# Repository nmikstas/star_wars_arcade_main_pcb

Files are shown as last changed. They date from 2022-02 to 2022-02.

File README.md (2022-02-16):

# star_wars_arcade_main_pcb
The source files for the reproduction of the 1983 Star Sars Arcade main PCB. The PCB is designed with Kicad. This project is complete and the PCB is verified working!

# Folder Structure
* BOM - Bill of materials for the main PCB
* Gerbers -The gerber files for the main PCB
* pcb - The Kicad design files for the main PCB

# PCB Specifications
* Layers: 2
* Dimensions: 293mm X 525mm
* Different PCB Design: 1
* PCB Thickness: 1.6mm
* Surface Finish: HASL
* Castellated Holes: No
* Copper Weight: 1oz.

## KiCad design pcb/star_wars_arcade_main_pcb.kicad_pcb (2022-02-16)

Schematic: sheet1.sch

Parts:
A_6, A_7: LS165A; DIP16
A_8: LS74; DIP14
A_9: LS164A; DIP14
B/C_0: LS138; DIP16
B_1: LS244B; DIP20
B_5: LS86; DIP14
B_6, B_7: LS165A; DIP16
B_8: LS385; DIP20
B_9: LS164A; DIP14
C1, C4, C5, C7, C8, C9, C10, C11, C12, C13, C14, C15, C16, C17, C18, C19, C20, C21, C22, C23, C24, C45, C46, C47, C48, C52, C53, C54, C55, C56, C57, C58, C59, C60, C61, C62, C63, C64, C65, C66, C67, C68, C69, C70, C71, C72, C73, C74, C75, C76, C77, C78, C79, C80, C81, C82, C83, C84, C85, C86, C87, C88, C89, C90, C91, C92, C95, C96: .1uf; GenericComp
C2: 100pf; CapBrown
C3: 39pf; CapBrown
C49, C50, C51: 100uf 35V; LargeCap
C93: 10uf 25V; Cap1
C94: 4.7uf; Cap1
CR1, CR3: 1N914; GenericComp
CR2: BLUE; LED
CR4, CR5, CR6: BLUE LED; LED
C_1: LS244C; DIP20
C_2: 68B09E; DDIP40
C_5: LS164A; DIP14
C_6, C_7: LS384; DIP16
C_8: LS08; DIP14
C_9, C_10: LS161; DIP16
D/E0: LS245A; DIP20
D_3: LS191_; DIP16
D_4, D_6, D_7: LS299; DIP20
D_5: LS164A; DIP14
D_8: LS00; DIP14
D_9: LS161; DIP16
E/F_2: LS244D; DIP20
E_1: x2212; DIP18
E_3: LS191_; DIP16
E_4: LS245A; DIP20
E_5, E_6: LS08; DIP14
E_7: LS00; DIP14
E_8: S02; DIP14
E_9: LS244; DIP20
F/H_2: 137211; DDIP24
F_1: 27128; DIP28
F_3: LS191_; DIP16
F_4: LS245A; DIP20
F_5: RAM; DDIP24
F_6: LS153A; DIP16
F_7: LS00; DIP14
F_8: S10; DIP14
F_9: LS244; DIP20
H/J_1: 2764; DIP28
H_3: LS157A; DIP16
H_4: LS245A; DIP20
H_5: RAM; DDIP24
H_6: LS191_; DIP16
H_7: PROM; DIP18
H_8: LS74; DIP14
H_9: LS244E; DIP20
J16: Aud_Conn; Aud_Con
J17: Main_Connector; J17
J18: Cat_Box_Conn; J21
J20: J20; Edge_Connector
J/K_1: 2764; DIP28
J_2: LS139; DIP16
J_3: LS153A; DIP16
J_4: LS244A; DIP20
J_5: LS164A; DIP14
J_6: LS191_; DIP16
J_7: PROM; DIP18
J_9: LS244F; DIP20
K/L_1: 2764; DIP28
K_2, K_6: LS08; DIP14
K_3: LS153A; DIP16
K_4: LS244A; DIP20
K_5: LS164A; DIP14
K_7: PROM; DIP18
K_8: LS04; DIP14
K_9: ADC; DIP28
L1: 100uH; Ind
L/M_9: LS259; DIP16
L_2, L_8: LS138; DIP16
L_3: LS157B; DIP16
L_4, L_5: LS374; DIP20
L_6: LS175D; DIP16
L_7: PROM; DIP18
L_10: 7407; DIP14
M_1: 2764; DIP28
M_2: LS74; DIP14
M_3: LS00; DIP14
M_4: LS374A; DIP20
M_5: LS374B; DIP20
M_6: LS83A; DIP16
M_7: LS299; DIP20
M_8: LS138; DIP16
N_1: S04; DIP14
N_2: LS161; DIP16
N_3: LS299; DIP20
N_4, N_5, N_6: LS83A; DIP16
N_7: LS138; DIP16
N_8: LS00; DIP14
N_11: 082; DIP8
P_2: LS393; DIP14
P_3: LS04; DIP14
P_4: LS175B; DIP16
P_5: LS175A; DIP16
P_6: LS175C; DIP16
P_7: LS74; DIP14
P_8: LS109; DIP16
Q1: 2N3904; GenericTrans
Q3, Q4: Q_NPN_BCE; VoltReg
R1, R2, R5, R11, R12, R15, R42, R43, R44, R45, R46, R47, R48, R49, R50, R51, R52, R53, R54, R55, R56, R57, R59: 10k; GenericComp
R3: 68; GenericComp
R4, R9, R10, R13, R14, R16, R17, R22, R23, R24, R25, R34, R35, R36, R37, R38, R39, R40, R41, R58, R91, R92, R93, R94, R95, R96, R97: 1k; GenericComp
R6: 100k; GenericComp
R7: 220; GenericComp
R8: 15k; GenericComp
R18, R19, R20, R21, R26, R27, R28, R29, R30, R31, R32, R33: 470; GenericComp
R79, R80, R81: 100; GenericComp
R82, R83, R84, R85, R86: 4.7k; GenericComp
R100: 22k; GenericComp
R1000: 180; GenericComp
R_2: LS393A; DIP14
R_3: LS161; DIP16
R_5: LS155; DIP16
R_6: LS74; DIP14
R_8: LS191_; DIP16
R_10: LS14; DIP14
SPARE1: SpareB; DIP16
SW1: L_11; DIP8
SW2: D_10; DIP16
SW3: E/F_10; DIP16
TP3MHZ1, TP6MHZ1: TP; TEST_POINT
TP+5V1, TP+5V2, TP+5V3, TP+5V4, TP+10.3UN1, TP+12V1: TP; TEST_POINT
TP-5V1: TP; TEST_POINT
TPCATSTR1: TP; TEST_POINT
TPCOINL1: TP; TEST_POINT
TPCOINR1: TP; TEST_POINT
TPCOIN_AUX1: TP; TEST_POINT
TPDIAGN1: TP; TEST_POINT
TPE1: TP; TEST_POINT
TPEVMEM1: TP; TEST_POINT
TPFIRE/START1: TP; TEST_POINT
TPGND1, TPGND2, TPGND3, TPGND4: TP; TEST_POINT
TPHALT1: TP; TEST_POINT
TPMPAGE1: TP; TEST_POINT
TPQ1: TP; TEST_POINT
TPRESET1: TP; TEST_POINT
TPROM0, TPROM1, TPROM2, TPROM3, TPROM4: TP; TEST_POINT
TPRST1, TPRST2: TP; TEST_POINT
TPRW1: TP; TEST_POINT
TPRWB1: TP; TEST_POINT
TPSELF_TEST1: TP; TEST_POINT
TPSLAM1: TP; TEST_POINT
TPWDDIS1: TP; TEST_POINT
VR1: L7805; VoltReg
Y1: 12.096MHz; Y

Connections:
1.5GCLK: D_9.12 (QC), F_7.13
1.5MHZ: B_1.11 (I0b), D_8.5, E_5.9, E_5.10, E_5.12, E_5.13, M_2.2 (1D), M_3.4, N_2.12 (QC), P_3.1
3GCLK: D_9.13 (QB), E_7.1
3MHZ: B_1.6 (I2a), C_5.8 (CLK), D_4.12 (CK~), D_5.8 (CLK), M_2.3 (1CLK), N_2.13 (QB), N_8.2, TP3MHZ1.1, TP3MHZ1.2
3MHZ*: M_3.13, M_4.11 (Cp), M_5.11 (Cp), M_7.3 (G2~), N_3.3 (G2~), P_8.10 (Q), R_6.11 (2CLK)
6MHZ: B_1.8 (I3a), N_2.14 (QA), P_3.11, TP6MHZ1.1, TP6MHZ1.2
12MHZ: C_9.2 (CLK), C_10.2 (CLK), D_9.2 (CLK), E_8.8, E_8.11, N_1.12, N_2.2 (CLK), R1000.1
750KHZ: K_9.10 (CLK), N_2.11 (QD), P_2.13 (2CK), R85.2
+5EAROM: C93.1, C95.2, CR3.1 (K), E_1.18 (VCC), R100.1, VR1.3 (OUT)
+5V: A_6.16 (VCC), A_7.16 (VCC), A_8.14 (VCC), A_9.14 (VCC), B/C_0.16 (VCC), B_1.20 (VCC), B_5.14 (VCC), B_6.16 (VCC), B_7.16 (VCC), B_8.20 (VCC), B_9.14 (VCC), C1.1, C5.1, C21.1, C22.1, C23.1, C24.1, C45.1, C49.1, C52.1, C53.1, C54.1, C55.1, C56.1, C57.1, C58.1, C59.1, C60.1, C61.1, C62.1, C63.1, C64.1, C65.1, C66.1, C67.1, C68.1, C69.1, C70.1, C71.1, C72.1, C73.1, C74.1, C75.1, C76.1, C77.1, C78.1, C79.1, C80.1, C81.1, C82.1, C83.1, C84.1, C85.1, C86.1, C87.1, C88.1, C89.1, C90.1, C91.1, C92.1, C96.1, CR1.1 (K), CR4.2 (A), CR5.2 (A), CR6.2 (A), C_1.20 (VCC), C_2.7 (VCC), C_5.14 (VCC), C_6.16 (VCC), C_7.16 (VCC), C_8.14 (VCC), C_9.16 (VCC), C_10.16 (VCC), D/E0.20 (VCC), D_3.16 (VCC), D_4.20 (VCC), D_5.14 (VCC), D_6.20 (VCC), D_7.20 (VCC), D_8.14 (VCC), D_9.16 (VCC), E/F_2.20 (VCC), E_3.16 (VCC), E_4.20 (VCC), E_5.14 (VCC), E_6.14 (VCC), E_7.14 (VCC), E_8.14 (VCC), E_9.20 (VCC), F/H_2.24 (VCC), F_1.1 (VPP), F_1.27 (PGM), F_1.28 (VCC), F_3.16 (VCC), F_4.20 (VCC), F_5.24 (VCC), F_6.16 (VCC), F_7.14 (VCC), F_8.14 (VCC), F_9.20 (VCC), H/J_1.1 (VPP), H/J_1.26 (NC), H/J_1.27 (PGM), H/J_1.28 (VCC), H_3.16 (VCC), H_4.20 (VCC), H_5.24 (VCC), H_6.16 (VCC), H_7.18 (VCC), H_8.14 (VCC), H_9.20 (VCC), J16.5 (+5V), J17.1 (5V0), J17.2 (5V0), J17.3 (5V0), J17.4 (5V0), J17.83 (5V0), J17.84 (5V0), J17.85 (5V0), J17.86 (5V0), J18.45 (5V0), J18.46 (5V0), J18.47 (5V0), J18.48 (5V0), J18.49 (5V0), J18.50 (5V0), J20.2 (+5V_REG), J20.21 (+SENSE), J20.B (+5V_REG), J20.Y (+5V_REG), J/K_1.1 (VPP), J/K_1.26 (NC), J/K_1.27 (PGM), J/K_1.28 (VCC), J_2.16 (VCC), J_3.16 (VCC), J_4.20 (VCC), J_5.14 (VCC), J_6.16 (VCC), J_7.18 (VCC), J_9.20 (VCC), K/L_1.1 (VPP), K/L_1.26 (NC), K/L_1.27 (PGM), K/L_1.28 (VCC), K_2.14 (VCC), K_3.16 (VCC), K_4.20 (VCC), K_5.14 (VCC), K_6.14 (VCC), K_7.18 (VCC), K_8.14 (VCC), K_9.11 (VCC), K_9.12 (REF+), L/M_9.16 (VCC), L_2.16 (VCC), L_3.16 (VCC), L_4.20 (VCC), L_5.20 (VCC), L_6.16 (VCC), L_7.18 (VCC), L_8.16 (VCC), L_10.14 (VCC), M_1.1 (VPP), M_1.26 (NC), M_1.27 (PGM), M_1.28 (VCC), M_2.14 (VCC), M_3.14 (VCC), M_4.20 (VCC), M_5.20 (VCC), M_6.5 (VCC), M_7.20 (VCC), M_8.16 (VCC), N_1.14 (VCC), N_2.16 (VCC), N_3.20 (VCC), N_4.5 (VCC), N_5.5 (VCC), N_6.5 (VCC), N_7.16 (VCC), N_8.14 (VCC), N_11.2 (-), P_2.14 (VCC), P_3.14 (VCC), P_4.16 (VCC), P_5.16 (VCC), P_6.16 (VCC), P_7.14 (VCC), P_8.16 (VCC), Q1.3 (C), R1.1, R4.1, R10.2, R11.2, R12.2, R15.2, R16.2, R17.2, R18.1, R19.1, R20.1, R21.1, R26.1, R27.1, R28.1, R29.1, R30.1, R31.1, R32.1, R33.1, R42.1, R43.1, R44.1, R45.1, R46.1, R47.1, R48.1, R49.1, R50.1, R51.1, R52.1, R53.1, R54.1, R55.1, R56.1, R57.1, R82.1, R83.1, R84.1, R85.1, R86.1, R91.1, R92.2, R93.2, R94.2, R95.2, R96.2, R97.1, R_2.14 (VCC), R_3.16 (VCC), R_5.16 (VCC), R_6.14 (VCC), R_8.16 (VCC), R_10.14 (VCC), SPARE1.16 (VCC), TP+5V1.1, TP+5V1.2, TP+5V2.1, TP+5V2.2, TP+5V3.1, TP+5V3.2, TP+5V4.1, TP+5V4.2
+10V: C4.1, J20.18 (+10_UNREG), J20.E (+10_UNREG), N_11.8 (VCC), R5.2, TP+10.3UN1.1, TP+10.3UN1.2
+12V: C51.1, J16.7 (+12V), J20.20 (+12VDC), J20.C (+12VDC), TP+12V1.1, TP+12V1.2, VR1.1 (IN)
-5V: C50.2, J16.6 (-5V), J20.19 (-5VDC), J20.D (-5VDC), TP-5V1.1, TP-5V1.2
A0: C_1.17 (I3b), C_2.8 (A0), J18.17 (A0)
A1: C_1.6 (I2a), C_2.9 (A1), J18.18 (A1)
A2: C_1.4 (I1a), C_2.10 (A2), J18.15 (A2)
A3: C_1.2 (I0a), C_2.11 (A3), J18.16 (A3)
A4: C_1.8 (I3a), C_2.12 (A4), J18.13 (A4)
A5: C_1.15 (I2b), C_2.13 (A5), J18.14 (A5)
A6: C_1.13 (I1b), C_2.14 (A6), J18.11 (A6)
A7: C_1.11 (I0b), C_2.15 (A7), J18.12 (A7)
A8: B_1.17 (I3b), C_2.16 (A8), J18.9 (A8)
A9: B_1.15 (I2b), C_2.17 (A9), J18.10 (A9)
A10: B_1.13 (I1b), C_2.18 (A10), J18.7 (A10)
A11: B_1.4 (I1a), C_2.19 (A11), J18.8 (A11)
A12: B_1.2 (I0a), C_2.20 (A12), J18.21 (A12)
A13: C_2.21 (A13), J18.22 (A13), K_2.9
A14: B/C_0.2 (B), C_2.22 (A14), J18.19 (A14)
A15: B/C_0.3 (C), C_2.23 (A15), J18.20 (A15), M_3.9
AB0: C_1.3 (O3b), E_1.6 (A0), F/H_2.8 (AB0), F_1.10 (A0), H/J_1.10 (A0), J17.43 (AB0), J17.44 (AB0), J/K_1.10 (A0), J_2.14 (2A), K/L_1.10 (A0), K_9.25 (ADDA), L/M_9.1 (A), M_1.10 (A0), N_7.1 (A), R83.2, R_5.3 (A1)
AB1: C_1.14 (O2a), E_1.5 (A1), F/H_2.7 (AB1), F_1.9 (A1), H/J_1.9 (A1), J17.35 (AB1), J17.36 (AB1), J/K_1.9 (A1), J_2.13 (2B), K/L_1.9 (A1), K_9.24 (ADDB), L/M_9.2 (B), L_3.14 (4A), M_1.9 (A1), N_7.2 (B), R82.2
AB2: C_1.16 (O1a), E_1.4 (A2), F/H_2.6 (AB2), F_1.8 (A2), H/J_1.8 (A2), J17.33 (AB2), J17.34 (AB2), J/K_1.8 (A2), K/L_1.8 (A2), L/M_9.3 (C), L_3.2 (1A), M_1.8 (A2), N_7.3 (C)
AB3: C_1.18 (O0a), E_1.3 (A3), F/H_2.5 (AB3), F_1.7 (A3), H/J_1.7 (A3), J17.31 (AB3), J17.32 (AB3), J/K_1.7 (A3), J_3.10 (2C0), K/L_1.7 (A3), M_1.7 (A3)
AB4: C_1.12 (O3a), E_1.2 (A4), F/H_2.4 (AB4), F_1.6 (A4), H/J_1.6 (A4), J17.45 (AB4), J17.46 (AB4), J/K_1.6 (A4), K/L_1.6 (A4), K_3.10 (2C0), M_1.6 (A4)
AB5: C_1.5 (O2b), E_1.16 (A5), F/H_2.3 (AB5), F_1.5 (A5), H/J_1.5 (A5), J17.37 (AB5), J17.38 (AB5), J/K_1.5 (A5), J_3.6 (1C0), K/L_1.5 (A5), L_8.1 (A), M_1.5 (A5), M_8.1 (A)
AB6: C_1.7 (O1b), E_1.17 (A6), F/H_2.2 (AB6), F_1.4 (A6), H/J_1.4 (A6), J17.41 (AB6), J17.42 (AB6), J/K_1.4 (A6), K/L_1.4 (A6), K_3.6 (1C0), L_8.2 (B), M_1.4 (A6), M_8.2 (B)
AB7: C_1.9 (O0b), E_1.1 (A7), F/H_2.1 (AB7), F_1.3 (A7), F_6.6 (1C0), H/J_1.3 (A7), J17.39 (AB7), J17.40 (AB7), J/K_1.3 (A7), K/L_1.3 (A7), L_8.3 (C), M_1.3 (A7), M_8.3 (C)
AB8: B_1.3 (O3b), F/H_2.23 (AB8), F_1.25 (A8), H/J_1.25 (A8), H_3.14 (4A), J17.47 (AB8), J17.48 (AB8), J/K_1.25 (A8), K/L_1.25 (A8), L_2.1 (A), M_1.25 (A8)
AB9: B_1.5 (O2b), F/H_2.22 (AB9), F_1.24 (A9), H/J_1.24 (A9), H_3.2 (1A), J17.49 (AB9), J17.50 (AB9), J/K_1.24 (A9), K/L_1.24 (A9), L_2.2 (B), M_1.24 (A9)
AB10: B_1.7 (O1b), F/H_2.19 (AB10), F_1.21 (A10), H/J_1.21 (A10), H_3.5 (2A), J17.51 (AB10), J17.52 (AB10), J/K_1.21 (A10), K/L_1.21 (A10), L_2.3 (C), M_1.21 (A10)
AB11: B_1.16 (O1a), F_1.23 (A11), H/J_1.23 (A11), H_3.11 (3A), J17.53 (AB11), J17.54 (AB11), J/K_1.23 (A11), J_2.2 (1A), K/L_1.23 (A11), M_1.23 (A11)
AB12: B_1.18 (O0a), F_1.2 (A12), H/J_1.2 (A12), J17.59 (AB12), J17.60 (AB12), J/K_1.2 (A12), J_2.3 (1B), K/L_1.2 (A12), M_1.2 (A12)
AB13: B/C_0.1 (A), J17.55 (AB13), J17.56 (AB13), K_2.8
BIC0: E_3.3 (QA), J_3.11 (2C1)
BIC1: E_3.2 (QB), K_3.11 (2C1)
BIC2: E_3.6 (QC), J_3.5 (1C1)
BIC3: E_3.7 (QD), K_3.5 (1C1)
BIC4: F_3.3 (QA), F_6.5 (1C1)
BIC5: F_3.2 (QB), H_3.13 (4B)
BIC6: F_3.6 (QC), H_3.3 (1B)
BIC7: F_3.7 (QD), H_3.6 (2B)
BIC8: D_3.3 (QA), H_3.10 (3B)
CIG*: K_5.2 (B), M_3.12, R_6.9 (2Q)
COIN_AUX: J20.P (COIN_AUX), R32.2, R39.2
COIN_CNTR_1: C7.1, J20.7 (COIN_CNTR_1), Q3.2 (C), SW1.1
COIN_CNTR_2: C8.1, J20.H (COIN_CNTR_2), Q4.2 (C), SW1.8
COIN_L: J20.N (COIN_L), R31.2, R40.2
COIN_R: J20.12 (COIN_R), R30.2, R41.2
D0: C_2.31 (D0), D/E0.11 (B7), E/F_2.18 (O0a), E_1.12 (IO1), E_4.11 (B7), E_9.3 (O3b), F/H_2.9 (D0), F_9.3 (O3b), H_9.7 (O1b), J18.29 (D0), J_9.3 (O3b), K_9.17 (D0)
D1: C_2.30 (D1), D/E0.12 (B6), E/F_2.16 (O1a), E_1.13 (IO2), E_4.12 (B6), E_9.5 (O2b), F/H_2.10 (D1), F_9.5 (O2b), H_9.16 (O1a), J18.30 (D1), J_9.5 (O2b), K_9.14 (D1)
D2: C_2.29 (D2), D/E0.13 (B5), E/F_2.12 (O3a), E_1.14 (IO3), E_4.13 (B5), E_9.7 (O1b), F/H_2.11 (D2), F_9.7 (O1b), H_9.18 (O0a), J18.27 (D2), J_9.7 (O1b), K_9.15 (D2)
D3: C_2.28 (D3), D/E0.14 (B4), E/F_2.3 (O3b), E_1.15 (IO4), E_4.14 (B4), E_9.9 (O0b), F/H_2.13 (D3), F_9.9 (O0b), H_9.3 (O3b), J18.28 (D3), J_9.16 (O1a), K_9.8 (D3)
D4: C_2.27 (D4), D/E0.15 (B3), E/F_2.5 (O2b), E_4.15 (B3), E_9.12 (O3a), F/H_2.14 (D4), F_9.12 (O3a), H_9.9 (O0b), J18.25 (D4), J_9.12 (O3a), K_9.18 (D4)
D5: C_2.26 (D5), D/E0.16 (B2), E/F_2.14 (O2a), E_4.16 (B2), E_9.14 (O2a), F/H_2.15 (D5), F_9.14 (O2a), H_9.12 (O3a), J18.26 (D5), J_9.14 (O2a), K_9.19 (D5)
D6: C_2.25 (D6), D/E0.17 (B1), E/F_2.7 (O1b), E_4.17 (B1), E_9.16 (O1a), F/H_2.16 (D6), F_9.16 (O1a), H_9.14 (O2a), J18.23 (D6), J_9.9 (O0b), K_9.20 (D6)
D7: C_2.24 (D7), D/E0.18 (B0), E/F_2.9 (O0b), E_4.18 (B0), E_9.18 (O0a), F/H_2.17 (D7), F_9.18 (O0a), H_9.5 (O2b), J18.24 (D7), J_9.18 (O0a), K_9.21 (D7), L/M_9.13 (D)
DB0: D_3.15 (A), D_4.16 (H~), E_3.15 (A), E_4.9 (A7), F_4.11 (B7), H_4.11 (B7), H_6.10 (C), J_4.12 (O3a), K_4.12 (O3a), L_4.13 (D4), L_5.18 (D7), L_6.13 (D3), P_4.5 (D1)
DB1: D_4.4 (G~), E_3.1 (B), E_4.8 (A6), F_4.12 (B6), H_4.12 (B6), H_6.9 (D), J_4.14 (O2a), K_4.14 (O2a), L_4.7 (D2), L_5.17 (D6), L_6.12 (D2), P_4.12 (D2)
DB2: D_4.15 (F~), E_3.10 (C), E_4.7 (A5), F_4.13 (B5), H_4.13 (B5), J_4.16 (O1a), J_6.15 (A), K_4.16 (O1a), L_4.14 (D5), L_5.14 (D5), P_4.13 (D3), P_6.13 (D3)
DB3: D_4.5 (E~), E_3.9 (D), E_4.6 (A4), F_4.14 (B4), H_4.14 (B4), J_4.18 (O0a), J_6.1 (B), K_4.18 (O0a), L_4.8 (D3), L_5.13 (D4), L_6.4 (D0), P_4.4 (D0)
DB4: D_4.14 (D~), E_4.5 (A3), F_3.15 (A), F_4.15 (B3), H_4.15 (B3), J_4.3 (O3b), J_6.10 (C), K_4.3 (O3b), L_4.18 (D7), L_5.8 (D3), L_6.5 (D1), P_5.12 (D2)
DB5: D_4.6 (C~), E_4.4 (A2), F_3.1 (B), F_4.16 (B2), H_4.16 (B2), J_4.5 (O2b), J_6.9 (D), K_4.5 (O2b), L_4.17 (D6), L_5.7 (D2), P_5.5 (D1), P_6.5 (D1)
DB6: D_4.13 (B~), E_4.3 (A1), F_3.10 (C), F_4.17 (B1), H_4.17 (B1), J_4.7 (O1b), K_4.7 (O1b), L_4.4 (D1), L_5.4 (D1), P_5.4 (D0), P_6.4 (D0), P_7.12 (2D)
DB7: D_4.7 (A~), E_4.2 (A0), F_3.9 (D), F_4.18 (B0), H_4.18 (B0), H_8.2 (1D), J_4.9 (O0b), K_4.9 (O0b), L_4.3 (D0), L_5.3 (D0), P_5.13 (D3), P_6.12 (D2)
DD0: L_5.19 (O7), M_5.19 (O7), M_6.11 (B1), M_7.16 (H~)
DD1: L_5.16 (O6), M_5.16 (O6), M_6.7 (B2), M_7.4 (G~)
DD2: L_5.15 (O5), M_5.15 (O5), M_6.4 (B3), M_7.15 (F~)
DD3: L_5.12 (O4), M_5.9 (O3), M_6.16 (B4), M_7.5 (E~)
DD4: L_5.9 (O3), M_5.12 (O4), M_7.14 (D~), N_6.11 (B1)
DD5: L_5.6 (O2), M_5.6 (O2), M_7.6 (C~), N_6.7 (B2)
DD6: L_5.5 (O1), M_5.5 (O1), M_7.13 (B~), N_6.4 (B3)
DD7: L_5.2 (O0), M_5.2 (O0), M_7.7 (A~), N_6.16 (B4)
DD8: L_4.12 (O4), M_4.9 (O3), N_3.16 (H~), N_4.11 (B1)
DD9: L_4.6 (O2), M_4.6 (O2), N_3.4 (G~), N_4.7 (B2)
DD10: L_4.15 (O5), M_4.15 (O5), N_3.15 (F~), N_4.4 (B3)
DD11: L_4.9 (O3), M_4.12 (O4), N_3.5 (E~), N_4.16 (B4)
DD12: L_4.19 (O7), M_4.2 (O0), N_3.14 (D~), N_5.11 (B1)
DD13: L_4.16 (O6), M_4.16 (O6), N_3.6 (C~), N_5.7 (B2)
DD14: L_4.5 (O1), M_4.5 (O1), N_3.13 (B~), N_5.4 (B3)
DD15: L_4.2 (O0), M_4.19 (O7), N_3.7 (A~), N_5.16 (B4)
DIAGN: J20.T (DIAGN), R18.2, R25.2
DS0: M_3.3, M_7.1 (S0~), N_3.1 (S0~)
DS1: M_7.19 (S1~), N_3.19 (S1~), N_8.8
E1.5MHZ: B_1.9 (O0b), J17.75 (1.5MHZ), J17.76 (1.5MHZ)
E3MHZ: B_1.14 (O2a), J17.69 (3MHZ), J17.70 (3MHZ)
E6MHZ: B_1.12 (O3a), J17.67 (6MHZ), J17.68 (6MHZ)
E12MHZ: J17.73 (12MHZ), J17.74 (12MHZ), N_1.10
ECLKQ: C_2.35 (Q), J17.77 (ECLKQ), J17.78 (ECLKQ), M_2.6 (~1Q), TPQ1.1, TPQ1.2
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

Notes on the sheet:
POWER INPUT
CLOCK
DIVIDER CLOCK GENERATOR
QUOTIENT SHIFT REGISTER
DIVIDEND SHIFT REGISTER
DIVIDEND LATCH
DIVIDER CONTROL
DIFFERENCE LATCH
ADDER
DIVISOR INVERTING LATCH
MICROPROCESSOR
POWER-ON RESET
WATCHDOG
INTERRUPT TIMER
ROM
RAM
NON_VOLATILE RAM
ADDRESS DECODERS
MATH ADDRESS DECODERS
TEST AND CONTROL SIGNALS
COIN DOOR OUTPUT
COIN DOOR AND CONTROL PANEL INPUT
OPTION SWITCHES
PSEUDO-RANDOM NUMBER GENERATOR
ANALOG/DIGITAL CONVERTER
MATRIX PROCESSOR ADDRESS SELECTOR
MATRIX PROCESSOR RAM
INSTRUCTION PROM
INSTRUCTION STROBE GATES
ACCUMULATOR
SERIAL SUBTRACTOR
REGISTER A
REGISTER B
SERIAL MULTIPLIER
MULTIPLIER/ACCUMULATOR CLOCK
MATRIX PROCESSOR CLOCK
BLOCK INDEX COUNTER
MATRIX PROCESSOR ADDRESS COUNTER
MATRIX PROCESSOR DATA SELECTOR
ADDRESS AND DATA SELECTOR CONTROL

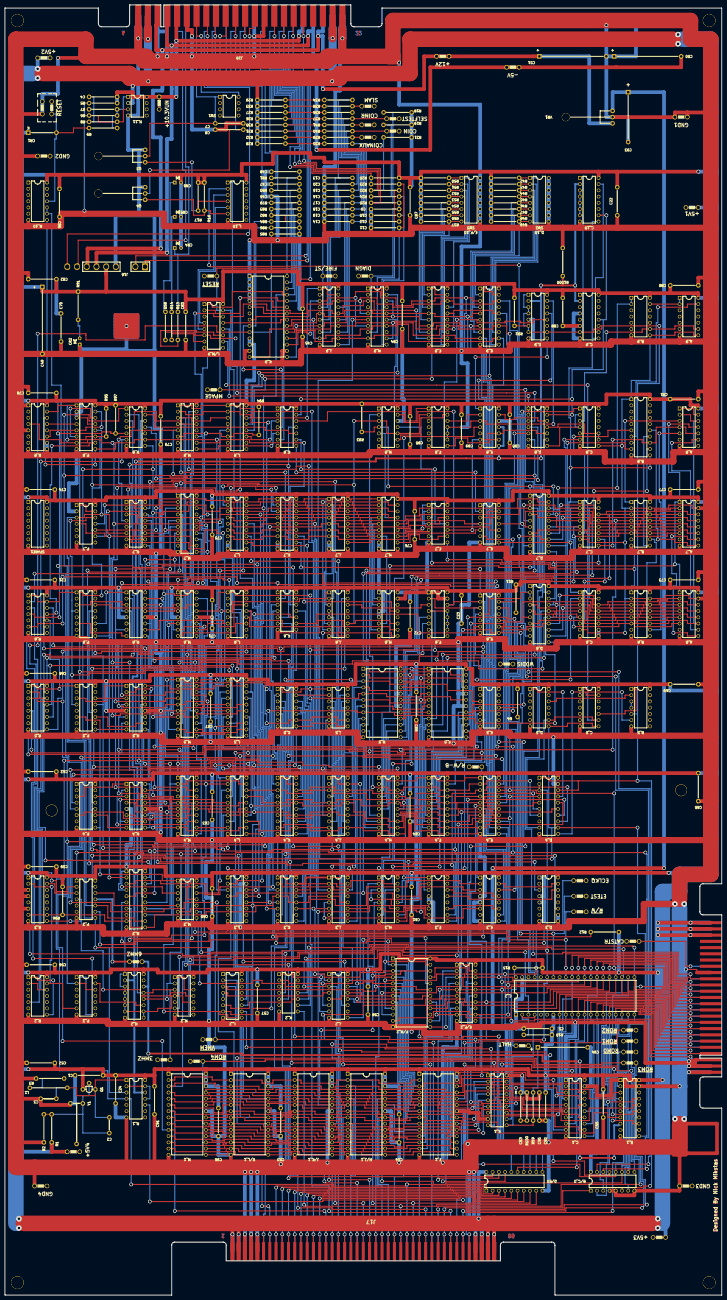
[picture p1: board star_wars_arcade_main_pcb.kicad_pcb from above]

Board: 2 copper layers, 292.1 x 525.8 mm, 317 parts (0 on the bottom side), 439 nets.

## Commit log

2021-04-28 Started work on the schematic capture
    [file6078F703.sch, sheet1.sch, star_wars_arcade_main_pcb.kicad_pcb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]
2021-04-28 Continued with the schematic
    [sheet1.sch]
2021-04-28 Finished microprocessor schematic page
    [sheet1.sch]
2021-04-29 Added ROM to schematic
    [sheet1.sch]
2021-04-30 Added RAM to the schematic
    [sheet1.sch]
2021-05-01 Continued work on the schematic
    [sheet1.sch]
2021-05-04 Worked on the schematic
    [sheet1.sch]
2021-05-05 Worked on the mathbox schematic
    [sheet1.sch]
2021-05-06 Continued the schematic
    [sheet1.sch]
2021-05-07 Completed the schematic but not error checking
    [sheet1.sch]
2021-05-07 Fixed most schematic errors
    [sheet1.sch]
2021-05-23 Fixed all errors on the schematic
    [sheet1.sch]
2021-05-29 Began the PCB layout
    [sheet1.sch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]
2021-05-31 Placed all the ICs
    [sheet1.sch, star_wars_arcade_main_pcb.kicad_pcb]
2021-06-01 Added power traces and components
    [sheet1.sch, star_wars_arcade_main_pcb.kicad_pcb]
2021-06-02 Added more power traces and components
    [sheet1.sch, star_wars_arcade_main_pcb.kicad_pcb]
2021-06-02 Added more components
    [sheet1.sch, star_wars_arcade_main_pcb.kicad_pcb]
2021-06-03 Added more power traces
    [sheet1.sch, star_wars_arcade_main_pcb.kicad_pcb]
2021-06-04 Finished the power traces
    [sheet1.sch, star_wars_arcade_main_pcb.kicad_pcb]
2021-06-05 Added several components
    [sheet1.sch, star_wars_arcade_main_pcb.kicad_pcb]
2021-06-06 Finished placing all components
    [star_wars_arcade_main_pcb.kicad_pcb]
2021-06-06 Added mounting holes
    [star_wars_arcade_main_pcb.kicad_pcb]
2021-06-07 Started adding signal traces
    [star_wars_arcade_main_pcb.kicad_pcb]
2021-06-07 Added more signal traces
    [star_wars_arcade_main_pcb.kicad_pcb]
2021-06-11 Added more signal traces, 951 disconnected signals remain
    [star_wars_arcade_main_pcb.kicad_pcb]
2021-06-12 891 unconnected signal remain
    [sheet1.sch, star_wars_arcade_main_pcb.kicad_pcb]
2021-06-15 661 unconnected signal remain
    [sheet1.sch, star_wars_arcade_main_pcb.kicad_pcb]
2021-06-16 557 unconnected signals remain
    [sheet1.sch, star_wars_arcade_main_pcb.kicad_pcb]
2021-06-21 241 unconnected signals remain
    [star_wars_arcade_main_pcb.kicad_pcb]
2021-06-21 63 disconnected signals remain
    [sheet1.sch, star_wars_arcade_main_pcb.kicad_pcb]
2021-06-22 Completed the layout!
    [sheet1.sch, star_wars_arcade_main_pcb.kicad_pcb]
2021-06-23 Updated readme file
    [star_wars_arcade_main_pcb-B_Cu.gbr, star_wars_arcade_main_pcb-B_Mask.gbr, star_wars_arcade_main_pcb-B_Paste.gbr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]
2021-07-13 Added BOM and fixed minor silkscreen issues
    [star_wars_arcade_main_pcb-B_Cu.gbr, star_wars_arcade_main_pcb-B_Mask.gbr, star_wars_arcade_main_pcb-B_SilkS.gbr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]
2021-07-13 Updated the BOM
2021-07-18 Fixed some minor silkscreen and BOM issues
    [star_wars_arcade_main_pcb.kicad_pcb]
2022-02-16 Updated BOM, test points on PCB and readme file
    [star_wars_arcade_main_pcb-B_Cu.gbr, star_wars_arcade_main_pcb-B_Mask.gbr, star_wars_arcade_main_pcb-B_SilkS.gbr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]
